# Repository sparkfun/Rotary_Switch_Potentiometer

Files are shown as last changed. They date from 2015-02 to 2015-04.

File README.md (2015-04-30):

Rotary Switch Potentiometer
========================================

Breakout board for 10-position rotary switch that allows you to add resistors to configure it as a custom stepped potentiometer.

[Rotary Switch Potentiometer
*Rotary Switch Potentiometer (BOB-13099)*](https://www.sparkfun.com/products/13099)

The Rotary Switch Potentiometer is a board that allows you to add some resistors to our one of our 10-position rotary switches, turning it into a potentiometer with ten discrete steps.  [The hookup guide can be found here.](https://learn.sparkfun.com/tutorials/rotary-switch-potentiometer-hookup-guide)

More information can be found on the Wiki for this repo. 

This part was created in Eagle v7.1.0, and the demonstration Arduino sketch was written in  Arduino v1.6.1. 

Repository Contents
-------------------
* **/Firmware** - An Arduino sketch to interface with the board. 
* **/Hardware** - All Eagle design files (.brd, .sch, .STL)
* **/Theory** - Spreadsheet to calculate resistor values

Product Versions
----------------
* [BOB-13099](https://www.sparkfun.com/products/13099)- Breakout board itself.

Related Products
----------------

To make the best use of BOB-13099, you'll need some additional components.

* A [10 position Rotary Switch](https://www.sparkfun.com/products/13253).
* Some [resistors](https://www.sparkfun.com/products/10969).
* A [control](https://www.sparkfun.com/products/9998) or [chickenhead](https://www.sparkfun.com/products/9998) knob.
* [Straight](https://www.sparkfun.com/products/116) or [right-angle](https://www.sparkfun.com/products/553) snappable headers.

Version History
---------------
* [vExxFxxZxxHxxLxxSxx](URL for tag specific to this version) description 
* [vEyyFyyZyyHyyLyySyy](URL for tag specific to this version) description

License Information
-------------------
The hardware is released under [Creative Commons ShareAlike 4.0 International](https://creativecommons.org/licenses/by-sa/4.0/).
The code is beerware; if you see me (or any other SparkFun employee) at the local, and you've found our code helpful, please buy us a round!

Distributed as-is; no warranty is given.

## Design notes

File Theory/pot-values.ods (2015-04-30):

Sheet: Resistor values
To Use: Plug in resistor values in each of the green boxes.
The sheet will calculate the overall series resistance, the resistance from the wiper to each end, and the attenuation factor if the circuit is wired as a divider.
Resistor positions increase from 1 (fully counterclockwise) ..to 9 (fully clockwise).
Switch positions are numbered similarly from 1 (maximum counterclockwise) to 10 (max clockwise).
Resistor Position | Resistor Value | Switch Position | R (W to CW) | R (CCW to W) | Gain Coeff | divider in dB
1 | 10000 | 1 | 90000 | 0 | 0.0000 | -inf
2 | 10000 | 2 | 80000 | 10000 | 0.1111 | -19.08
3 | 10000 | 3 | 70000 | 20000 | 0.2222 | -13.06
4 | 10000 | 4 | 60000 | 30000 | 0.3333 | -9.54
5 | 10000 | 5 | 50000 | 40000 | 0.4444 | -7.04
6 | 10000 | 6 | 40000 | 50000 | 0.5556 | -5.11
7 | 10000 | 7 | 30000 | 60000 | 0.6667 | -3.52
8 | 10000 | 8 | 20000 | 70000 | 0.7778 | -2.18
9 | 10000 | 9 | 10000 | 80000 | 0.8889 | -1.02
 |  | 10 | 0 | 90000 | 1.0000 | 0
Overall Resistance (CCW to CW) | 90000
 |  |  |  |  | Vout = Vin * factor
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

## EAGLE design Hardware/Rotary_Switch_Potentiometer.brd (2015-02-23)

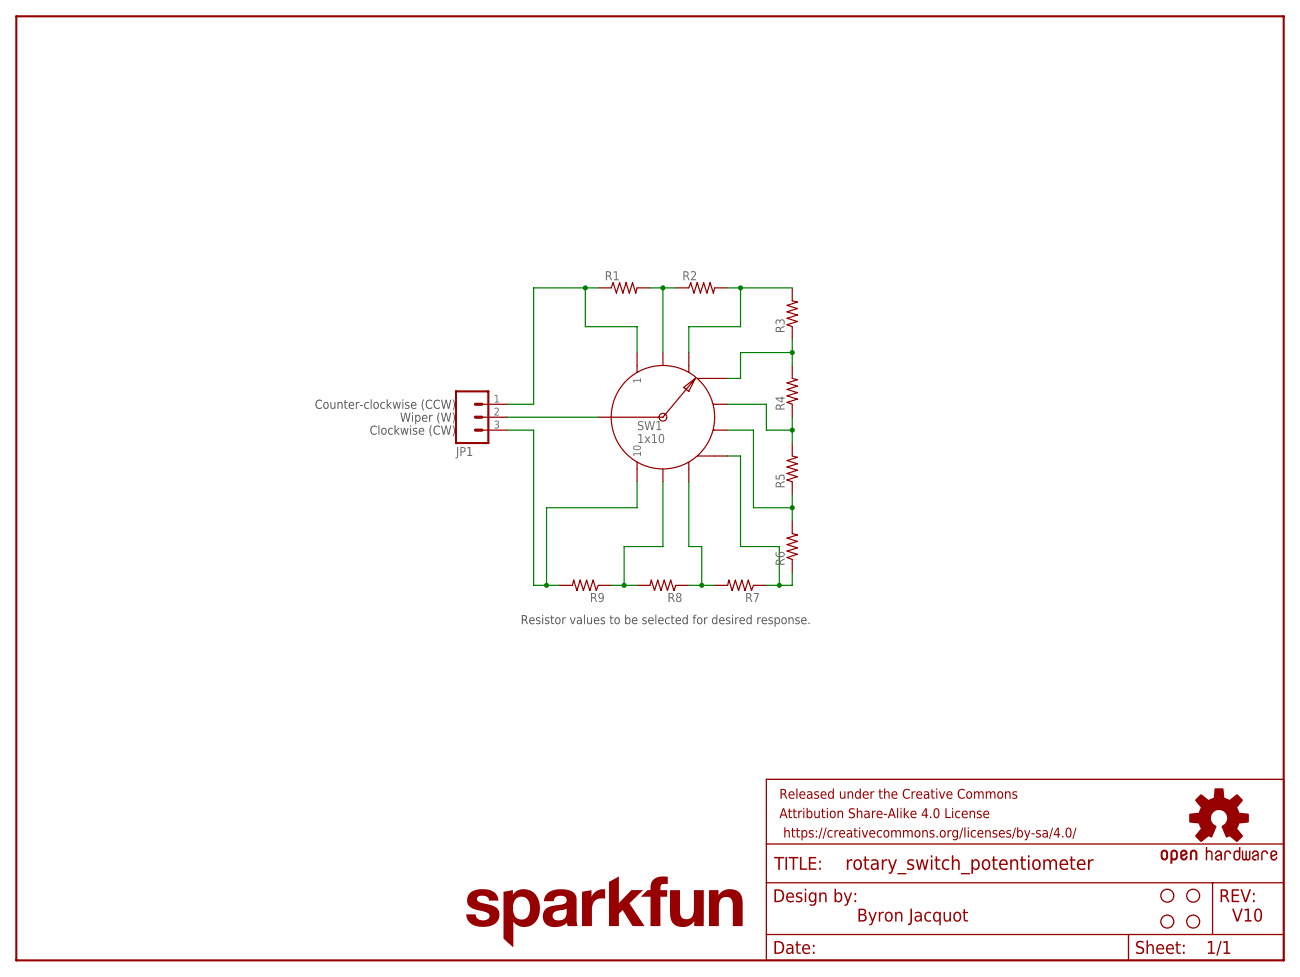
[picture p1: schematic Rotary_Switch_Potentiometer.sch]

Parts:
FRAME1: FRAME-LETTER; CREATIVE_COMMONS
JP1: M031X03_NO_SILK; 1X03_NO_SILK
LOGO1: OSHW-LOGOM; OSHW-LOGO-M
LOGO3: SFE_LOGO_NAME.1_INCH; SFE_LOGO_NAME_.1
R1, R2, R3, R4, R5, R6, R7, R8, R9: RESISTORPTH-1/4W-VERT-KIT; AXIAL-0.1EZ
STANDOFF1, STANDOFF2, STANDOFF5, STANDOFF6: STAND-OFF
SW1: 1x10; ROTARY_SWITCH_1X10_KIT

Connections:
unnamed: JP1.2, SW1.COMMON
unnamed: JP1.1, R1.P$1 (1), SW1.1
unnamed: JP1.3, R9.P$2 (2), SW1.10
unnamed: R7.P$2 (2), R8.P$1 (1), SW1.8
unnamed: R1.P$2 (2), R2.P$1 (1), SW1.2
unnamed: R2.P$2 (2), R3.P$2 (2), SW1.3
unnamed: R3.P$1 (1), R4.P$2 (2), SW1.4
unnamed: R4.P$1 (1), R5.P$2 (2), SW1.5
unnamed: R5.P$1 (1), R6.P$2 (2), SW1.6
unnamed: R6.P$1 (1), R7.P$1 (1), SW1.7
unnamed: R8.P$2 (2), R9.P$1 (1), SW1.9

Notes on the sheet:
Byron Jacquot
V10
Resistor values to be selected for desired response.
Wiper (W)
Counter-clockwise (CCW)
Clockwise (CW)

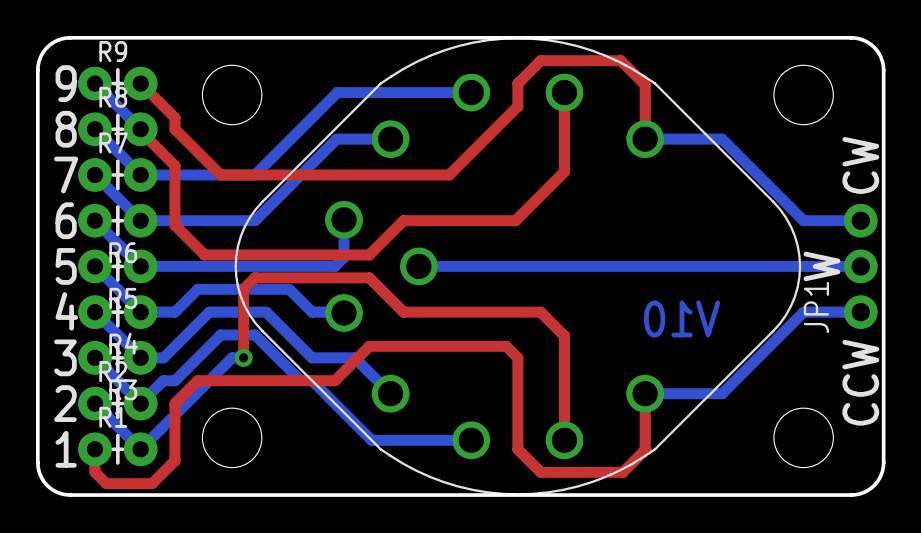
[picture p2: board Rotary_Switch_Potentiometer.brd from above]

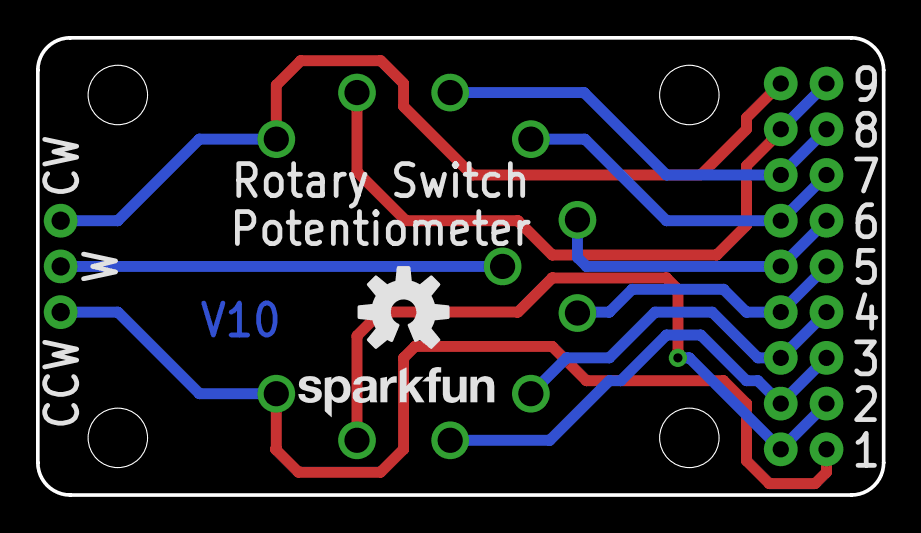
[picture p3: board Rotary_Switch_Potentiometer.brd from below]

Board: 2 copper layers, 47.0 x 25.4 mm, 18 parts (2 on the bottom side), 11 nets.

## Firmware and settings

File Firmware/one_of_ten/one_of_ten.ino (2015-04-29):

/******************************************************************************
one_of_ten.ino
Rotary Switch Potentiometer Example
By Byron Jacquot @ SparkFun Electronics
April 21, 2015
https://github.com/sparkfun/Rotary_Switch_Potentiometer

Demonstrates using the Rotary Switch Potentiometer breakout board 
with a microcontroller, to build a 10 position selector switch.

The Rotary Switch Potentiometer is a breakout board that adds 9 resistors to a
10 position rotary switch, to make a custom-taper, stepped potentiometer.  This
example uses 9 10KOhm resistors, and connects the rotary switch potentiometer
to an analog input.  The input is periodically scanned, and the current step
number is displayed on a 7-segment LED.

Development environment specifics:
This was developed using Arduino IDE 1.6.1
Using an Uno-compatible SparkFun RedBoard with a rotary switch potentiometer and
a 7-segment LED.

This code is beerware; if you see me (or any other SparkFun employee) at the
local, and you've found our code helpful, please buy us a round!

Distributed as-is; no warranty is given.
******************************************************************************/

/******************************************************************************
 Hardware connections
 --------------------
 
 The test configuration was wired as follows:
 
 The Rotary Switch Potentiometer board was populated with 10K resistors in 
 every position.  It was connected to the RedBoard as follows:
 
 RedBoard pin : Rotary Switch Potentiometer Pin
 ----------------------------------------------
 GND          : CCW
 A0           : W
 5V           : CW

 GPIO pins on the RedBoard drove the 7-segment display.  See the 7-segment 
 display datasheet for the pin number assignment
 (https://cdn.sparkfun.com/datasheets/Components/LED/YSD-160AR4B-8.pdf)
 
 RedBoard pin : Rotary Switch Potentiometer Pin
 ----------------------------------------------
 GND          : 3, 8 LED Anodes
 4            : 1, segment E
 5            : 2, segment D
 6            : 4, segment C
 7            : 5, decimal point
 8            : 6, segment B
 9            : 7, segment A
 10           : 9, segment F
 11           : 10, segment G
 
  ******************************************************************************/

// Bitmaps for display digits 0 through 9.
// Pin ordering corresponds to the connections described in the table above.
// This data is treated as active high - we'll invert it 
// when it's applied to the GPIO pins for the common-anode display
static const uint8_t font[10] = {0x77, 0x14, 0xb3, 0xb6, 0xd4, 0xe6, 0xe7, 0x34, 0xf7, 0xf4 };

// void drawLED(uint8_t val)
// Takes an input value and renders it on the 7-segment diaplay
// by driving each pin to the appropriate logic level for the character,
// as stored in the table above.
//
// It accepts a uint8_t as input, and truncates it to the 0-9 range.
void drawLED(uint8_t val)
{
  uint8_t idx = val % 10; // truncate input to 0 to 9 range.
  
  uint8_t mask = 0x01;
  for(uint8_t pin = 4; pin <= 11; pin++)
  {
    // Starting at output pin 4, step through to pin 11.
    // For each pin, check whether the corresponding bit in the font array
    // is set, and if so, illuminate that LED.  
    //
    // LED has inverse response - logic low turns it ON.
    // So if a bit in the font is high, set that pin low
    if(font[idx] & mask)
    {
      digitalWrite(pin, LOW);
    }
    else
    {
      digitalWrite(pin, HIGH);
    }
    
    mask <<= 1;
  }
  
  
}

void setup() 
{
  // put your setup code here, to run once:

  Serial.begin(9600);

  // initialize pins 4 through 11 as outputs.  
  pinMode(4, OUTPUT);
  pinMode(5, OUTPUT);
  pinMode(6, OUTPUT);
  pinMode(7, OUTPUT);

  pinMode(8, OUTPUT);
  pinMode(9, OUTPUT);
  pinMode(10, OUTPUT);
  pinMode(11, OUTPUT);

}

void loop() 
{
  // put your main code here, to run repeatedly:
  uint16_t input;
  uint16_t val;
  
  // read the ADC
  input = analogRead(0);
  
  // Translate ADC value from 0-1023 to 0-9.
  // This implements the proportion
  // input/1023 = val/9.
  // One "step" of the pot is about 113 ADC counts.
  // We're adding 65 (1/2 of 113) to the input value, so that the 
  // input is in the middle of the window, rather than right at the edge, so values 
  // are stable and solid.
  val = (input+56)*9/1023;
  
  // Take the calculated value and display it.
  drawLED(val);
}

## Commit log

2014-09-02 Initial Commit
    Boilerplate and board files.
    [Rotary_Switch_Potentiometer.brd, Rotary_Switch_Potentiometer.sch]
2014-09-02 Small schem update.
    [Rotary_Switch_Potentiometer.sch]
2014-09-03 Adding spreadsheet for divider calculations
    [pot-values.ods]
2015-02-21 Updates from working with protos.
    Now has 4 mounting holes.
    [Rotary_Switch_Potentiometer.brd, Rotary_Switch_Potentiometer.sch, pot-values.ods]
2015-02-23 Tweaks after engineering group review.
    [Rotary_Switch_Potentiometer.brd, Rotary_Switch_Potentiometer.sch]
2015-04-29 Updating documentation
    Improved spreadsheet, added Arduino sketch.
    [pot-values.ods]
2015-04-30 Fixing a few cell arguments in pot-values
    [pot-values.ods]

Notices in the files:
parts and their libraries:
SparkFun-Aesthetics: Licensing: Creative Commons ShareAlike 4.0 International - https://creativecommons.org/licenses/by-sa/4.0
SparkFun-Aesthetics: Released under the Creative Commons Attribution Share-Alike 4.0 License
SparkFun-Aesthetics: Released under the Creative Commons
